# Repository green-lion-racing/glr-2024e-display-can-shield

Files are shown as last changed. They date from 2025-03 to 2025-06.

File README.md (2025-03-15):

# CAN-Shield for STM32F469I-DISCO

STM32F469I-DISCO board compatible CAN shield.

### Overview

Provides 8V for the discovery board, from 12V car voltage.

Acts as can transciever for the discovery board.

Accessible screw terminals for buttons signals to the discovery board.

Can be directly slotted on to the board.

### Used parts

| Article | Description | Link | Quantity |
| --- | --- | --- | --- |
| STMircoelectronics L9615D013TR | 12V can transiever | https://www.mouser.de/ProductDetail/STMicroelectronics/L9615D013TR?qs=RNlBCa%2FBPH2bRRygw50SdQ%3D%3D | 1 |
| STMicroelectronics LF80CDT-TR | voltage regulator 12V -> 8V | https://www.mouser.de/ProductDetail/STMicroelectronics/LF80CDT-TR?qs=jjdktuRV%2FggWfgmU%252Bn%252BoRA%3D%3D | 1 |
| STMicroelectronics ESDCAN01-2BLY | dual-line TVS diode | https://www.mouser.de/ProductDetail/STMicroelectronics/ESDCAN01-2BLY?qs=Ok1pvOkw6%2FpNzC2RQnWwPA%3D%3D | 1 |
| Samsung CL10B104KB8NNNC | capacitor 100nF | https://www.mouser.de/ProductDetail/Samsung-Electro-Mechanics/CL10B104KB8NNNC?qs=349EhDEZ59rvGc2rLwVOdA%3D%3D | 2 |
| Vishay CRCW060368R1FKEA | resistor 68ohm | https://www.mouser.de/ProductDetail/Vishay-Dale/CRCW060368R1FKEA?qs=6z8JnUK2jyMngsBXu5il1A%3D%3D | 1 |
| WECO 950-FB-04 | 4-pin screw terminal | https://www.buerklin.com/de/p/weco/leiterplattenklemmen/20877004/08H410/ | 1 |
| WECO 950-FB-08 | 8-pin screw terminal | https://www.buerklin.com/de/p/weco/leiterplattenklemmen/20877008/08H420/ | 1 |
| Generic header | 8-pin header 2.54mm | | 1 |
| Generic header | 6-pin header 2.54mm | | 1 |
| Generic socket | 2x8-pin socket 2.54mm | | 1 |

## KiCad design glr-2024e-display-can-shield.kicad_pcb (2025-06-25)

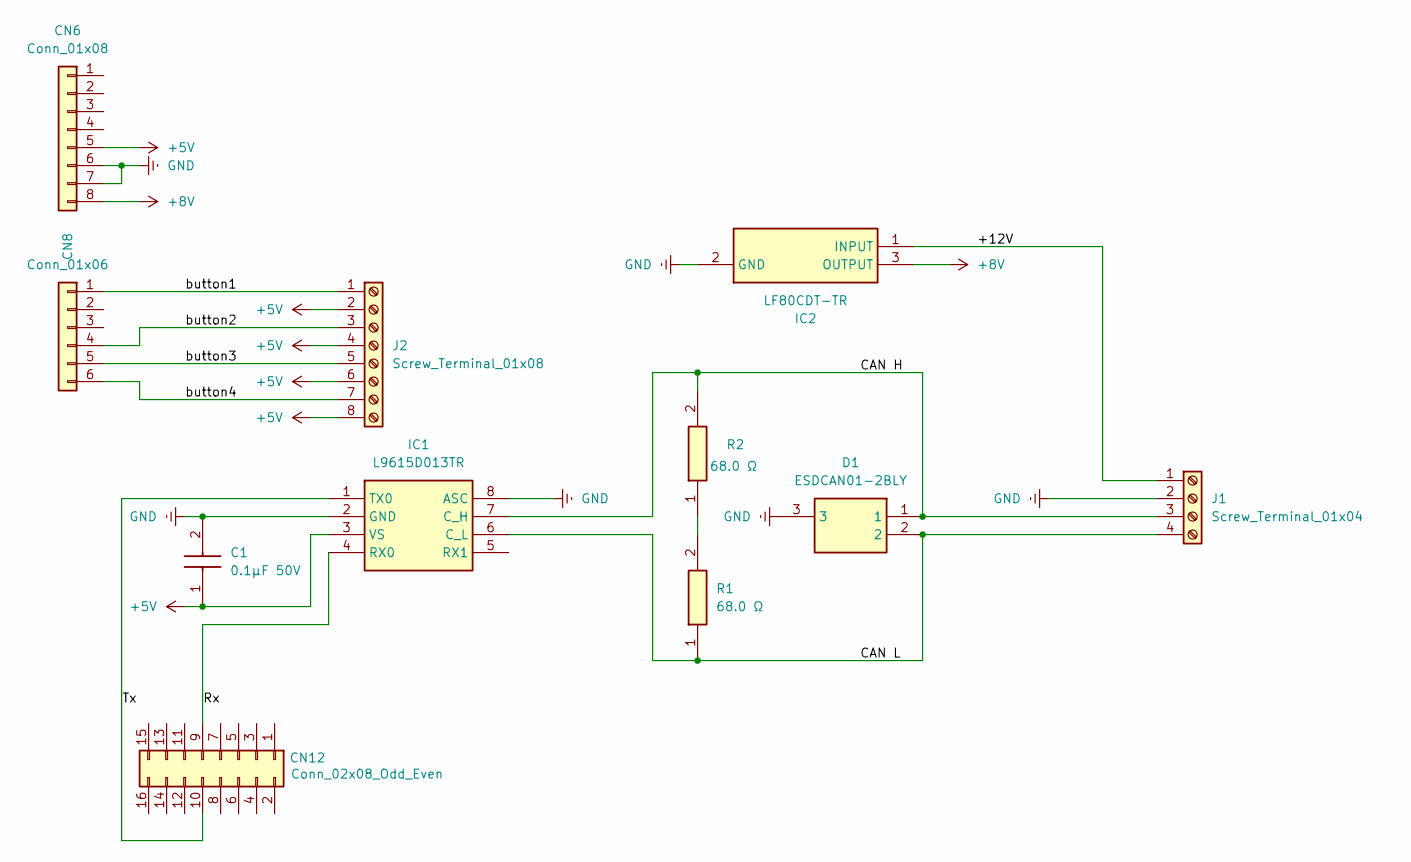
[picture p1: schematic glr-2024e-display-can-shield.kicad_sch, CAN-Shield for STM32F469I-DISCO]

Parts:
C1: 0.1μF 50V; CAPC1608X90N; Manufacturer_Part_Number CL10B104KB8NNNC
CN6: Conn_01x08; PinHeader_1x08_P2.54mm_Vertical
CN8: Conn_01x06; PinHeader_1x06_P2.54mm_Vertical
CN12: Conn_02x08_Odd_Even; PinSocket_2x08_P2.54mm_Vertical
D1: ESDCAN01-2BLY; SOT95P255X125-3N; Mouser Part Number 511-ESDCAN01-2BLY
IC1: L9615D013TR; SOIC127P600X175-8N; Manufacturer_Part_Number L9615D013TR; Mouser Part Number 511-L9615D-TR
IC2: LF80CDT-TR; LF80CDTTR; Mouser Part Number 511-LF80CDT-TR
J1: Screw_Terminal_01x04; WECO-950-FB-04
J2: Screw_Terminal_01x08; WECO-950-FB-08
R1, R2: 68.0 Ω; RESC1608X50N; Manufacturer_Part_Number CRCW060368R1FKEA

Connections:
+5V: C1.1, CN6.5, IC1.3 (VS), J2.2, J2.4, J2.6, J2.8
+8V: CN6.8, IC2.3 (OUTPUT)
/+12V: IC2.1 (INPUT), J1.1
/CAN H: D1.1, IC1.7 (C_H), J1.3, R2.2
/CAN L: D1.2, IC1.6 (C_L), J1.4, R1.1
/Rx: CN12.9, IC1.4 (RX0)
/Tx: CN12.10, IC1.1 (TX0)
/button1: CN8.1, J2.1
/button2: CN8.4, J2.3
/button3: CN8.5, J2.5
/button4: CN8.6, J2.7
GND: C1.2, CN6.6, CN6.7, D1.3, IC1.2 (GND), IC1.8 (ASC), IC2.2 (GND), J1.2
unnamed: R1.2, R2.1

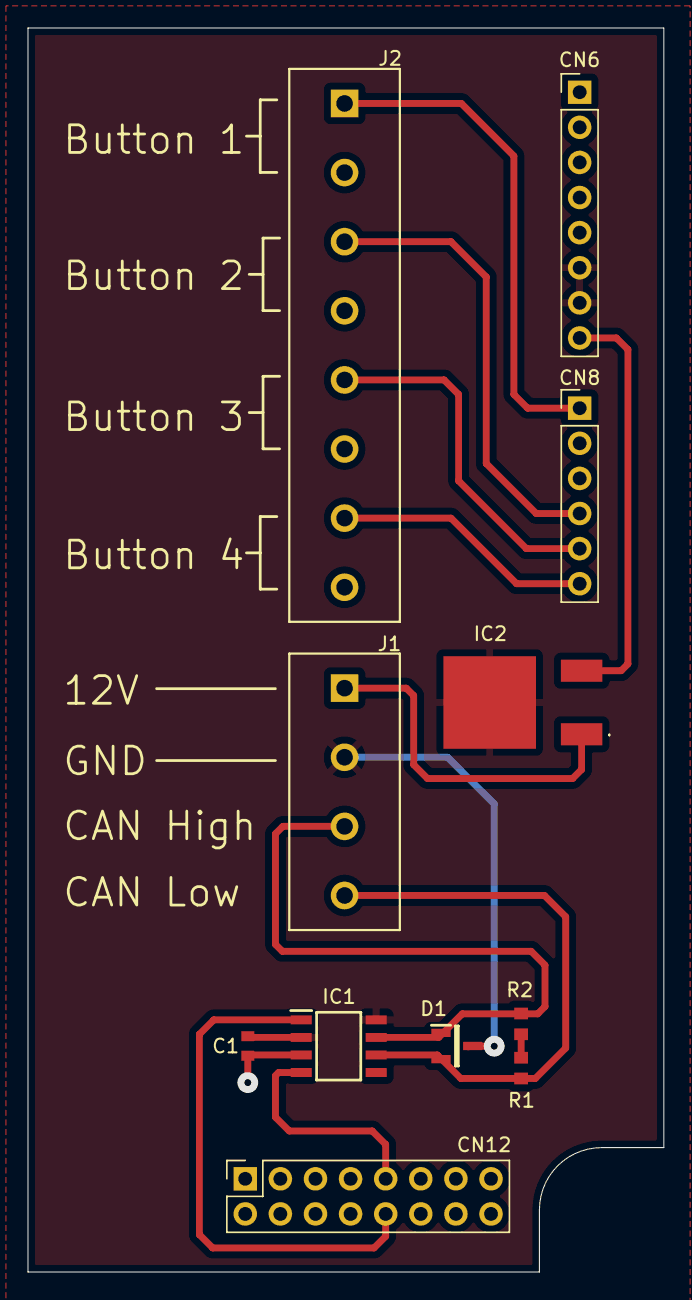
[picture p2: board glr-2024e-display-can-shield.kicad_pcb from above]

Board: 2 copper layers, 46.0 x 90.0 mm, 11 parts (0 on the bottom side), 13 nets.

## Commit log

2025-01-27 switch to KiCad 8
    [glr-2024e-display-can-shield.kicad_pcb, glr-2024e-display-can-shield.kicad_sch, glr-2024e-display-can-shield.sch]
2025-02-01 add initial pcb layout
    [glr-2024e-display-can-shield.kicad_pcb, glr-2024e-display-can-shield.kicad_sch]
2025-02-08 make 4pin and 8pin screw terminal instead of 12pin
    use exact footprint and 3d model
    [glr-2024e-display-can-shield.kicad_pcb, glr-2024e-display-can-shield.kicad_sch]
2025-02-15 add voltage regulator 12V -> 8V
    improve alignment of connectors
    add board outline
    add descriptions
    [glr-2024e-display-can-shield.kicad_pcb, glr-2024e-display-can-shield.kicad_sch]
2025-02-18 add board infos on pcb
    add two no GND zones
    [glr-2024e-display-can-shield.kicad_pcb]
2025-03-01 explicitly define which parts to use
    [glr-2024e-display-can-shield.kicad_pcb, glr-2024e-display-can-shield.kicad_sch]
2025-03-08 fix capacitor connection
    fix silk on terminal
    add output folder
    [glr-2024e-display-can-shield.kicad_pcb]
2025-03-15 add overview of needed parts
    move schematic kicad 8 -> kicad 9
    [glr-2024e-display-can-shield.kicad_sch]
2025-04-23 apply footprint change for WECO-950-FB-04/WECO-950-FB-08
    [glr-2024e-display-can-shield.kicad_pcb]
2025-06-25 use current date variable
    [glr-2024e-display-can-shield.kicad_pcb, glr-2024e-display-can-shield.kicad_sch]
